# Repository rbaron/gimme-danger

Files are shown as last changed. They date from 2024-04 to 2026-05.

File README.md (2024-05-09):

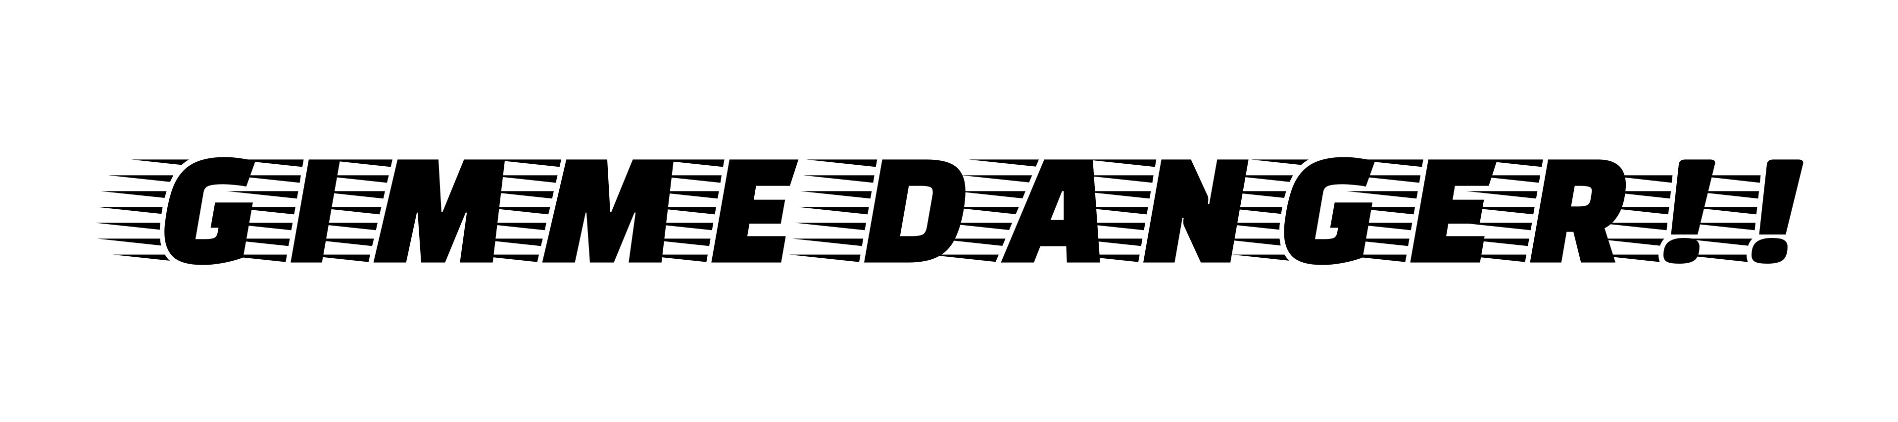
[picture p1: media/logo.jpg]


An open source [USB Power Delivery](https://en.wikipedia.org/wiki/USB_hardware#USB_Power_Delivery) trigger board and 5-channel PWM controller that runs [ESPHome](https://esphome.io).

_GIMME DANGER!!_ negotiates up to 21 V and 3 A[^1] from a USB Power Delivery (USB-PD) capable source -- such as common USB-C wall adapters/chargers and power banks -- and provides controls for its 5 PWM channels, optionally via [Home Assistant](https://home-assistant.io). Each channel can be used to interface with LEDs, motors and more. See below for some video demos.

# Hardware
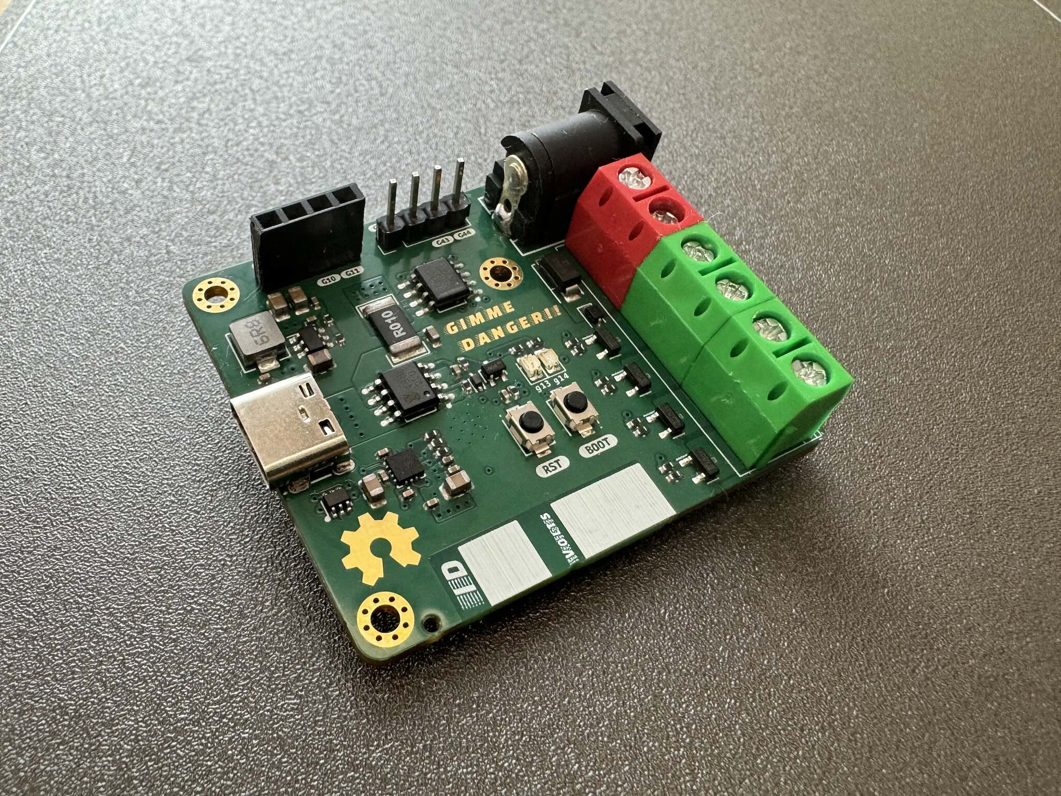
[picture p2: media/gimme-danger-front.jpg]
PCB front

* [ESP32-S3](https://www.espressif.com/en/products/socs/esp32-s3) module, mounted on the [back of the PCB](./media/gimme-danger-back.jpg)
* [FUSB302B](https://www.onsemi.com/products/interfaces/usb-type-c/fusb302b) USB-PD controller
* [INA219](https://www.ti.com/product/INA219) current sensor
* 5 output PWM channels
* 2x5.5mm barrel jack for raw output voltage access
* Optional OLED display

The [`kicad/`](./kicad/) directory contains design files and fabrication files for [JLCPCB](https://jlcpcb.com) manufacturing and assembly. The big through-hole components (headers, power terminals) and the ESP32-S3 module are not included in the assembly, and expected to be soldered by hand.

# Software
A custom `fusb302` component was implemented in ESPHome to support this project. It currently lives in its own fork on [github.com/rbaron/tree/fusb302](https://github.com/rbaron/esphome/tree/fusb302).

Here's a minimal example of using our custom `fusb302` component with ESPHome:

```yaml
external_components:
  - source:
      type: git
      url: https://github.com/rbaron/esphome
      ref: fusb302
    components: [fusb302]

fusb302:
  id: fusb302_id
  i2c_id: i2c_bus_fusb302
  interrupt_pin: GPIO5
  voltage: 12000 mV
  current: 1000 mA
  on_pd_negotiation_success:
    then:
      - switch.turn_on: load_switch
```

Full ESPHome configs for the demos below and more are available in the [`code/`](./code) directory.

# ‼️ Safety disclaimer ‼️
Configuration mistakes or software bugs may toast your devices if a high voltage is accidentally negotiated. While I have never run into these issues, even during development, be extra mindful of this fact then using this project or the `fusb302` component separately. For all intents and purposes, this is an experimental project. Use it at your own risk.

# Supported Power Delivery features
* USB-PD 2.0 Fixed voltages -- 5V, 9V, 12V, 15V, 20V
* USB-PD 3.0 Programmable Power Supply (PPS) -- 3.3V-21V, in 20mV steps (see the power supply demo below)
* USB-PD 3.1 Extended Power Range (EPR) Fixed PDOs -- 28V[^1]

Support for USB-PD 3.1 Adjustable Voltage Supply (AVS) in EPR mode will let us pull 15-28V[^1]. Unfortunately it's still difficult to get our hands on EPR AVS capable sources to implement and test support for it, but in theory the heavy lifting is already done.

# Some use cases & demos
Below there are some demo videos. Click on the images to play.

## 12V LED strip
The main motivation for this project was to power short runs of LED strips from USB-C chargers and control them via Home Assistant. Observing the maximum current and voltage[^1], it should be doable to light up a shelf, table, TV stand or any DYI project that requires only a couple of meters of 12V LED strips. Here [wled-calculator.github.io](https://wled-calculator.github.io/) should help with planning.

In the video below we see _GIMME DANGER!!_ connected to [Home Assistant](https://www.home-assistant.io), controlling a short 12V LED strip.
12V LED Strip (https://youtu.be/a7QtX55lgi8)

## 12V RGBW LED strip
RGBW LED Strip (https://youtu.be/ThnvIa4zbsM)

## A lil' programmable power supply
What's fun is that we can negotiate voltages on the fly from USB-PD 3.0 sources that offer Programmable Power Supply (PPS) modes. Here we have a potentiometer that sets the target voltage, and a button that triggers the USB-PD negotiation for that voltage.

A tiny, experimental and largely untested power supply that's powered by the same USB-C charger as my [soldering iron](https://pine64.com/product/pinecil-smart-mini-portable-soldering-iron/)? Straight into my toolbox.

Power Supply (https://youtu.be/3Acu_VfSuck)

## A Home Assistant controlled power supply
As a display of the flexibility of ESPHome and Home Assistant, we can use _GIMME DANGER!!_ to make a WiFi-controlled power supply. This is an objectively terrible idea, but it's not _GIMME SAFETY!!_ after all. Disregarding the risk of accidentally toasting our loads either via a misclick or a bug, this may be useful for automating the collection of I-V curves.

Home Assistant Power Supply (https://youtu.be/tXYciUaycYI)

# Optional OLED display
There are female pin headers on the board to connect an 0.91" OLED display like [this one from Aliexpress](https://aliexpress.com/item/1005004816561244.html). It's used to display the running voltage and current. There's also a cute animation when negotiation is succesful -- you can see it in the demos above.

# 3D printed case
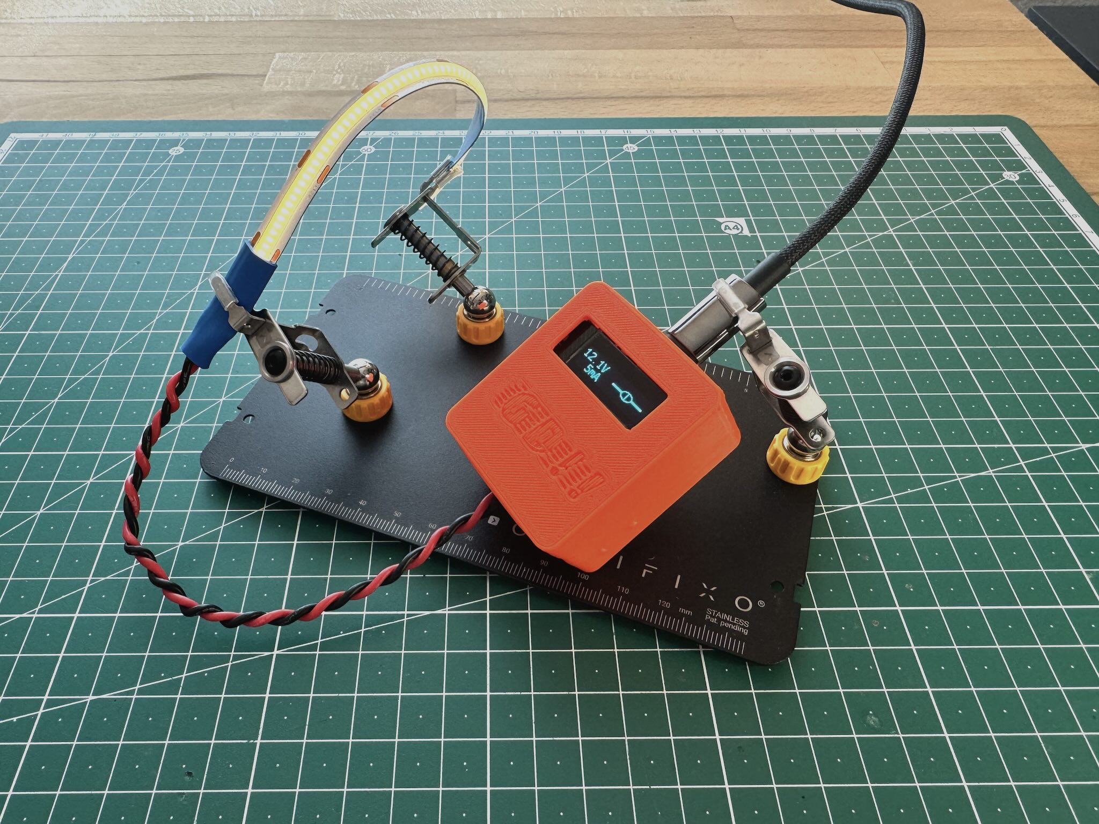
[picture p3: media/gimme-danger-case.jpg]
Case

The [`case/`](./case) directory contains a little 3D printable case. The PCB is optionally held in place by three M2 screws and threaded inserts.

# License
The hardware and associated design files are released under the [Creative Commons CC BY-SA 4.0](https://creativecommons.org/licenses/by-sa/4.0/) license. The code is released under the [MIT license](https://opensource.org/licenses/MIT).

# Attributions
The logo uses the [Faster One](https://fonts.google.com/specimen/Faster+One/about) font, released under the [Open Font License](https://openfontlicense.org/).

[^1]: FUSB302B's typical maximum voltage is 21 V, with 28 V as the absolute maximum. Each PWM channel is rated for 3 A. In theory the board supports up to 5 A, but a safer, better tested range is 21 V / 3 A in total.

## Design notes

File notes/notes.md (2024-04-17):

# Load Switch

Power dissipation:
- P = I^2 * R
- For 5A, Rdson = 30 mOhm, P = 0.75 W, say 1 W

- Digikey search [link](https://www.digikey.com/en/products/filter/single-fets-mosfets/278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)
- [AONR21321](https://aosmd.com/res/data_sheets/AONS21321.pdf)
  - -25 Vgsmax (no zenner needed)
  - 10 amps
  - $ 0.16 on JLCPCB C541711 (but only 260 available)
  - > 3W power dissipation
- [DMP3013](https://www.diodes.com/assets/Datasheets/DMP3013SFV.pdf)
  - -25 Vgsmax (no zenner needed)
  - 10 amps
  - $ 0.33 on JLCPCB (~ 3k available)
  - Only 900 mW of power dissipation?
- [Si7149ADP](https://www.vishay.com/docs/62839/si7149adp.pdf)
  - -25 Vgsmax (no zenner needed)
  - > 3W power dissipation
  - $ 1.30 on JLCPCB (only ~140 available)
- [AON6407](https://aosmd.com/res/data_sheets/AON6407.pdf)
  - -25 Vgsmax (no zenner needed)
  - Very low Rdson ~ 6 mOhm
  - Bigger footprint?
  - 85 A lol -- overkill? But does it matter? Downside: almost double footprint than AONR21321, but still small for us
  - 5W power dissipation
  - $ 0.5 on JLCPCB (7k available) C13899
  - Good choice
- [AO4407A](https://aosmd.com/res/data_sheets/AO4407A.pdf)
  - -25 Vgsmax (no zenner needed)
  - RDs ~ 20 mOhm @ 5 V
  - 12 A
  - > 2W power dissipation
  - $ 0.15 on JLCPCB (10k+ available) C16072
  - SOP-8 package, with the leads it's as big as the AO6407A above...
  - Good choice

### What if we go wild and aim for 3.1 EPR spec with max 48V?
#### Load Switch (P-channel)
- [Digikey search](https://www.digikey.ch/en/products/filter/transistors/fets-mosfets/single-fets-mosfets/278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)
- [DMP6023LE-13](https://wmsc.lcsc.com/wmsc/upload/file/pdf/v2/lcsc/1808280023_Diodes-Incorporated-DMP6023LE-13_C154901.pdf)
  - 28 mOhm
  - 1.3 W power dissipation
  - 1k+ available at JLCPCB
  - Good choice
- [AO4421](https://wmsc.lcsc.com/wmsc/upload/file/pdf/v2/lcsc/1809192244_Alpha---Omega-Semicon-AO4421_C33484.pdf)
  - 50 mOhm
  - 2 W power dissipation
  -
#### Channel Switch (N-channel)
- [AON2260](https://aosmd.com/sites/default/files/res/datasheets/AON2260.pdf)
  - 53 mOhm
  - 60V
  - Vth 2V
  - Rds at 3.3V too high
- [SSM3K341R](https://wmsc.lcsc.com/wmsc/upload/file/pdf/v2/lcsc/2201211430_TOSHIBA-SSM3K341R-LF_C2932178.pdf)
  - Rds at 3.3V too high
- [STS5NF60L](https://wmsc.lcsc.com/wmsc/upload/file/pdf/v2/lcsc/2001151031_STMicroelectronics-STS5NF60L_C457490.pdf)
  - Good, but expensive ($1)
  - Good Rdson at 3.3V, 5A
- [HL6003](https://wmsc.lcsc.com/wmsc/upload/file/pdf/v2/lcsc/2310251707_HL-6003_C7499845.pdf)
  - Works but max current 3A
  - But never heard of this brand
- Looks like we need an external BJT driver...

## Bidirectional switch
- [Digikey search](https://www.digikey.ch/en/products/filter/fet-mosfet-arrays/289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)
- [DMP3098LSD-13](https://jlcpcb.com/partdetail/DiodesIncorporated-DMP3098LSD13/C531177)
  - The one Phil uses
  - Dual P-channel MOSFET
  - Vgsmax = 20 V
  - Vds = -30 V
  - But Id is low: 3.3 A
- [AO4805](https://jlcpcb.com/parts/componentSearch?searchTxt=AO4805)
  - Good choice
  - 25 mOhm (kinda good for 2 MOSFETs)
- [DMP3028LSD-13](https://jlcpcb.com/partdetail/DiodesIncorporated-DMP3028LSD13/C397949)
  - Also good choice
  - Not as many available on JLCPCB

Use a BJT to drive the MOSFET gate?
- Inverts the signal (NOT gate)
- [DDTC1](https://datasheet.lcsc.com/lcsc/2304140030_Diodes-Incorporated-DDTC114EUA-7-F_C177021.pdf)
  - Self-biased (includes base and base-emitter resistors)
  - If we drive with 3.3V,
-

## Design
- [TI's bidirectional design with P-channel MOSFETs](https://www.ti.com/lit/an/slva948/slva948.pdf)
- [nxp load switch basics](https://www.nxp.com/docs/en/white-paper/NXP_Load_Switch_Basics.pdf)

## PWM drivers
Low side switching fine?
No need for high Vgsmax (we only switch between 0 and 3.3V).

- [AO3400A](https://aosmd.com/sites/default/files/res/data_sheets/AO3400A.pdf)
  - 5A
  - ~ 1W power dissipation
- [AON7410](https://datasheet.lcsc.com/lcsc/1808280434_Alpha---Omega-Semicon-AON7410_C269266.pdf)
  - 2W power dissipation
  -

## Barrel Jack
- [54-00131](https://tensility.s3.amazonaws.com/uploads/pdffiles/54-00131.pdf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)
  - 5.5mm OD, 2.1mm ID
  - 6A, 48V
  - Perfect
  - Not available on JLCPCB, but similar [DC-84](https://jlcpcb.com/partdetail/Jinjia-DC84/C718040) is
    - Rated for 2A, 30V only

## Regulator
- [TPS62175](https://www.ti.com/product/TPS62175)
- [TPS62932](https://www.ti.com/product/TPS62932)
  - Newer version
  - TPS62933DRLR
    - 600 available at JLC
    - $0.62
    - C3200405
- [TPS54302](https://www.ti.com/lit/ds/symlink/tps54302.pdf)
  - Cheap, ubiquituous

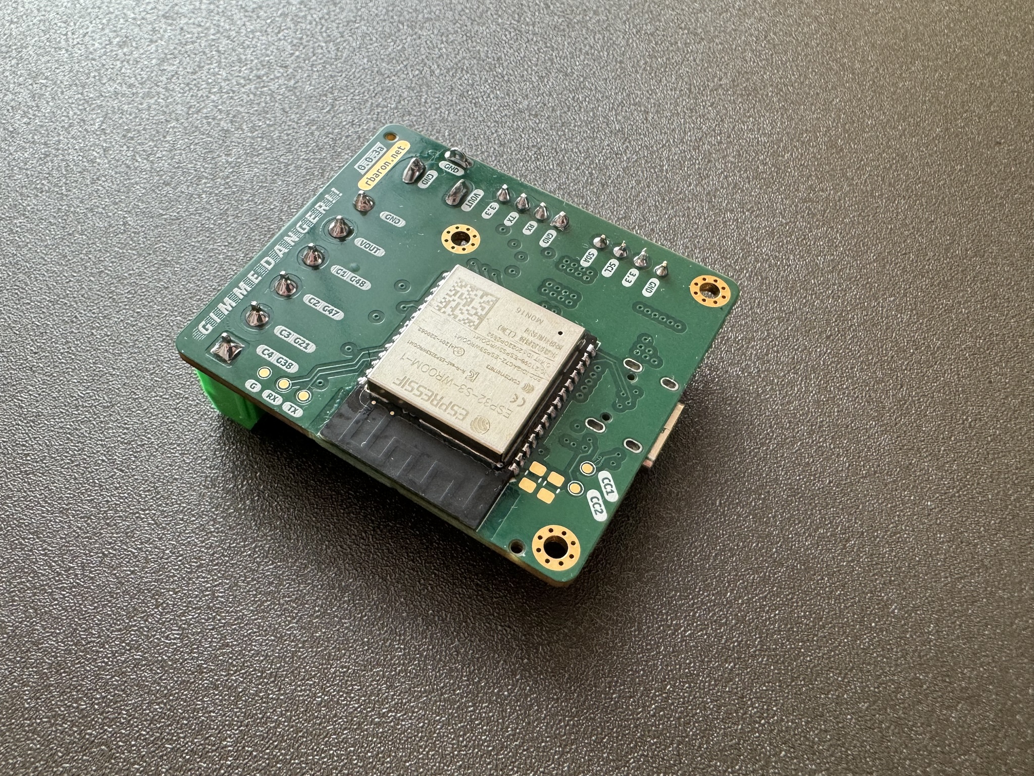
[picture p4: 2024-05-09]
media/gimme-danger-back.jpg

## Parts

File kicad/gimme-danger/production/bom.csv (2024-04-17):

Designator | Footprint | Quantity | Value | LCSC Part #
C1 | 0603 | 1 | 1u | C15849
C10, C14, C15, C2, C3, C9 | 0402 | 6 | 0.1u | C307331
C11, C8 | 0402 | 2 | 220p | C1530
C12 | 0402 | 1 | 1u | C52923
C13, C17, C18, C6 | 0805 | 4 | 22u | C45783
C4 | 0805 | 1 | 10u | C440198
C5, C7 | 0402 | 2 | 0.1u | C1525
D1 | 0805 | 1 | Red | C84256
D2 | 0805 | 1 | Green | C2297
D3 | D_SOD-323 | 1 | 1N5819WS
D4 | SOD-523_L1.2-W0.8-LS1.6-RD | 1 | 18V | C327501
D6 | SMA_L4.3-W2.5-LS5.0-RD | 1 | SMAJ48A | C353444
KEY2 | MLP-14_L2.5-W2.5-P0.50-BL-EP | 1 | FUSB302BMPX | C132291
L1 | IND-SMD_L4.5-W4.5_SMMS0420 | 1 | 6.8uH | C133194
Q1, Q2, Q3, Q4 | SOT-23 | 4 | AO3400A | C347475
R1, R11, R2, R3, R7 | 0402 | 5 | 4k7 | C25900
R10, R19, R20, R9 | 0402 | 4 | 330 | C25104
R12 | 0402 | 1 | 100k | C25741
R13 | 0402 | 1 | 22k | C25768
R14, R15, R17, R18, R4 | 0402 | 5 | 10k | C25744
R22 | 0402 | 1 | 33k | C25779
R23 | 0402 | 1 | 3.3k | C25890
R24 | R2512 | 1 | 10m | C105366
R5, R6 | 0402 | 2 | 1k | C11702
U10 | SOIC-8_L4.9-W3.9-P1.27-LS6.0-BL | 1 | AO4805 | C5183840
U11 | SOT-323-3_L2.0-W1.3-P1.30-LS2.1-BR | 1 | DDTC143EUA | C460045
U2 | USB-C_SMD-TYPE-C-31-M-12 | 1 | TYPE-C-31-M-12 | C165948
U3 | SC-70-6_L2.2-W1.3-P0.65-LS2.1-BL | 1 | TPD4E1U06DCKR | C194628
U5, U7 | SW-SMD_L3.9-W3.0-P4.45 | 2 | SKRKAEE020 | C115357
U8 | SOT-23-6 | 1 | TPS54302 | C311983
U9 | SOIC-8_L4.9-W3.9-P1.27-LS6.0-BL | 1 | INA219AIDR | C138706

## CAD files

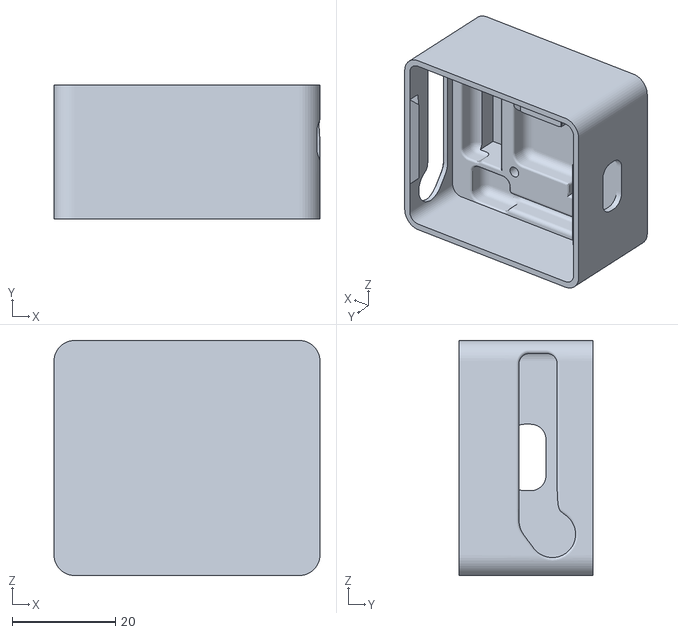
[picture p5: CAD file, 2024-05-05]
case/case.stl
51.5 x 26.0 x 45.5

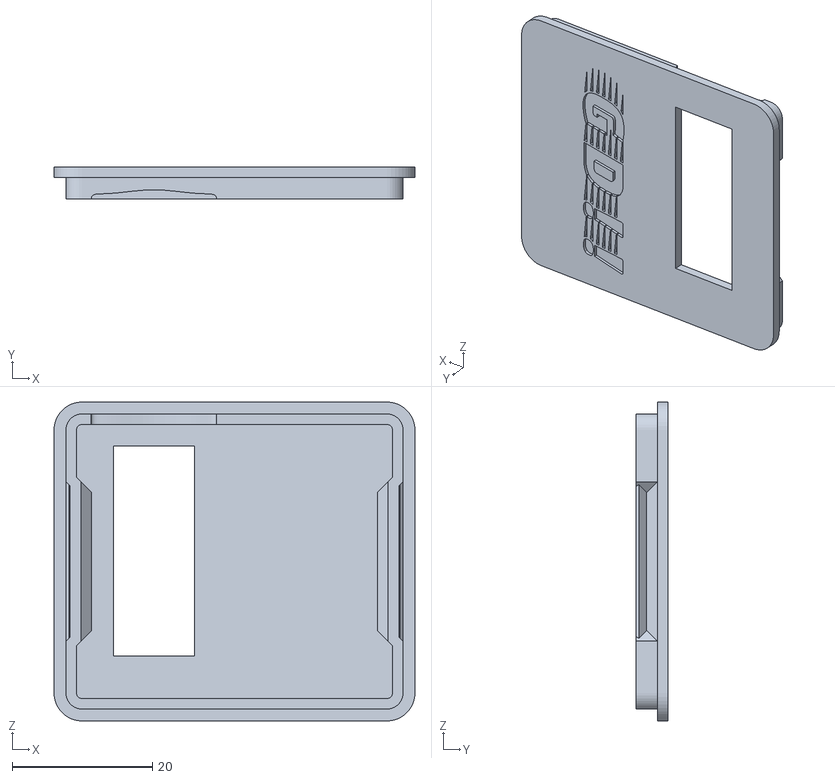
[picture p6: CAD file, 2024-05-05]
case/lid.stl
51.5 x 4.50 x 45.5

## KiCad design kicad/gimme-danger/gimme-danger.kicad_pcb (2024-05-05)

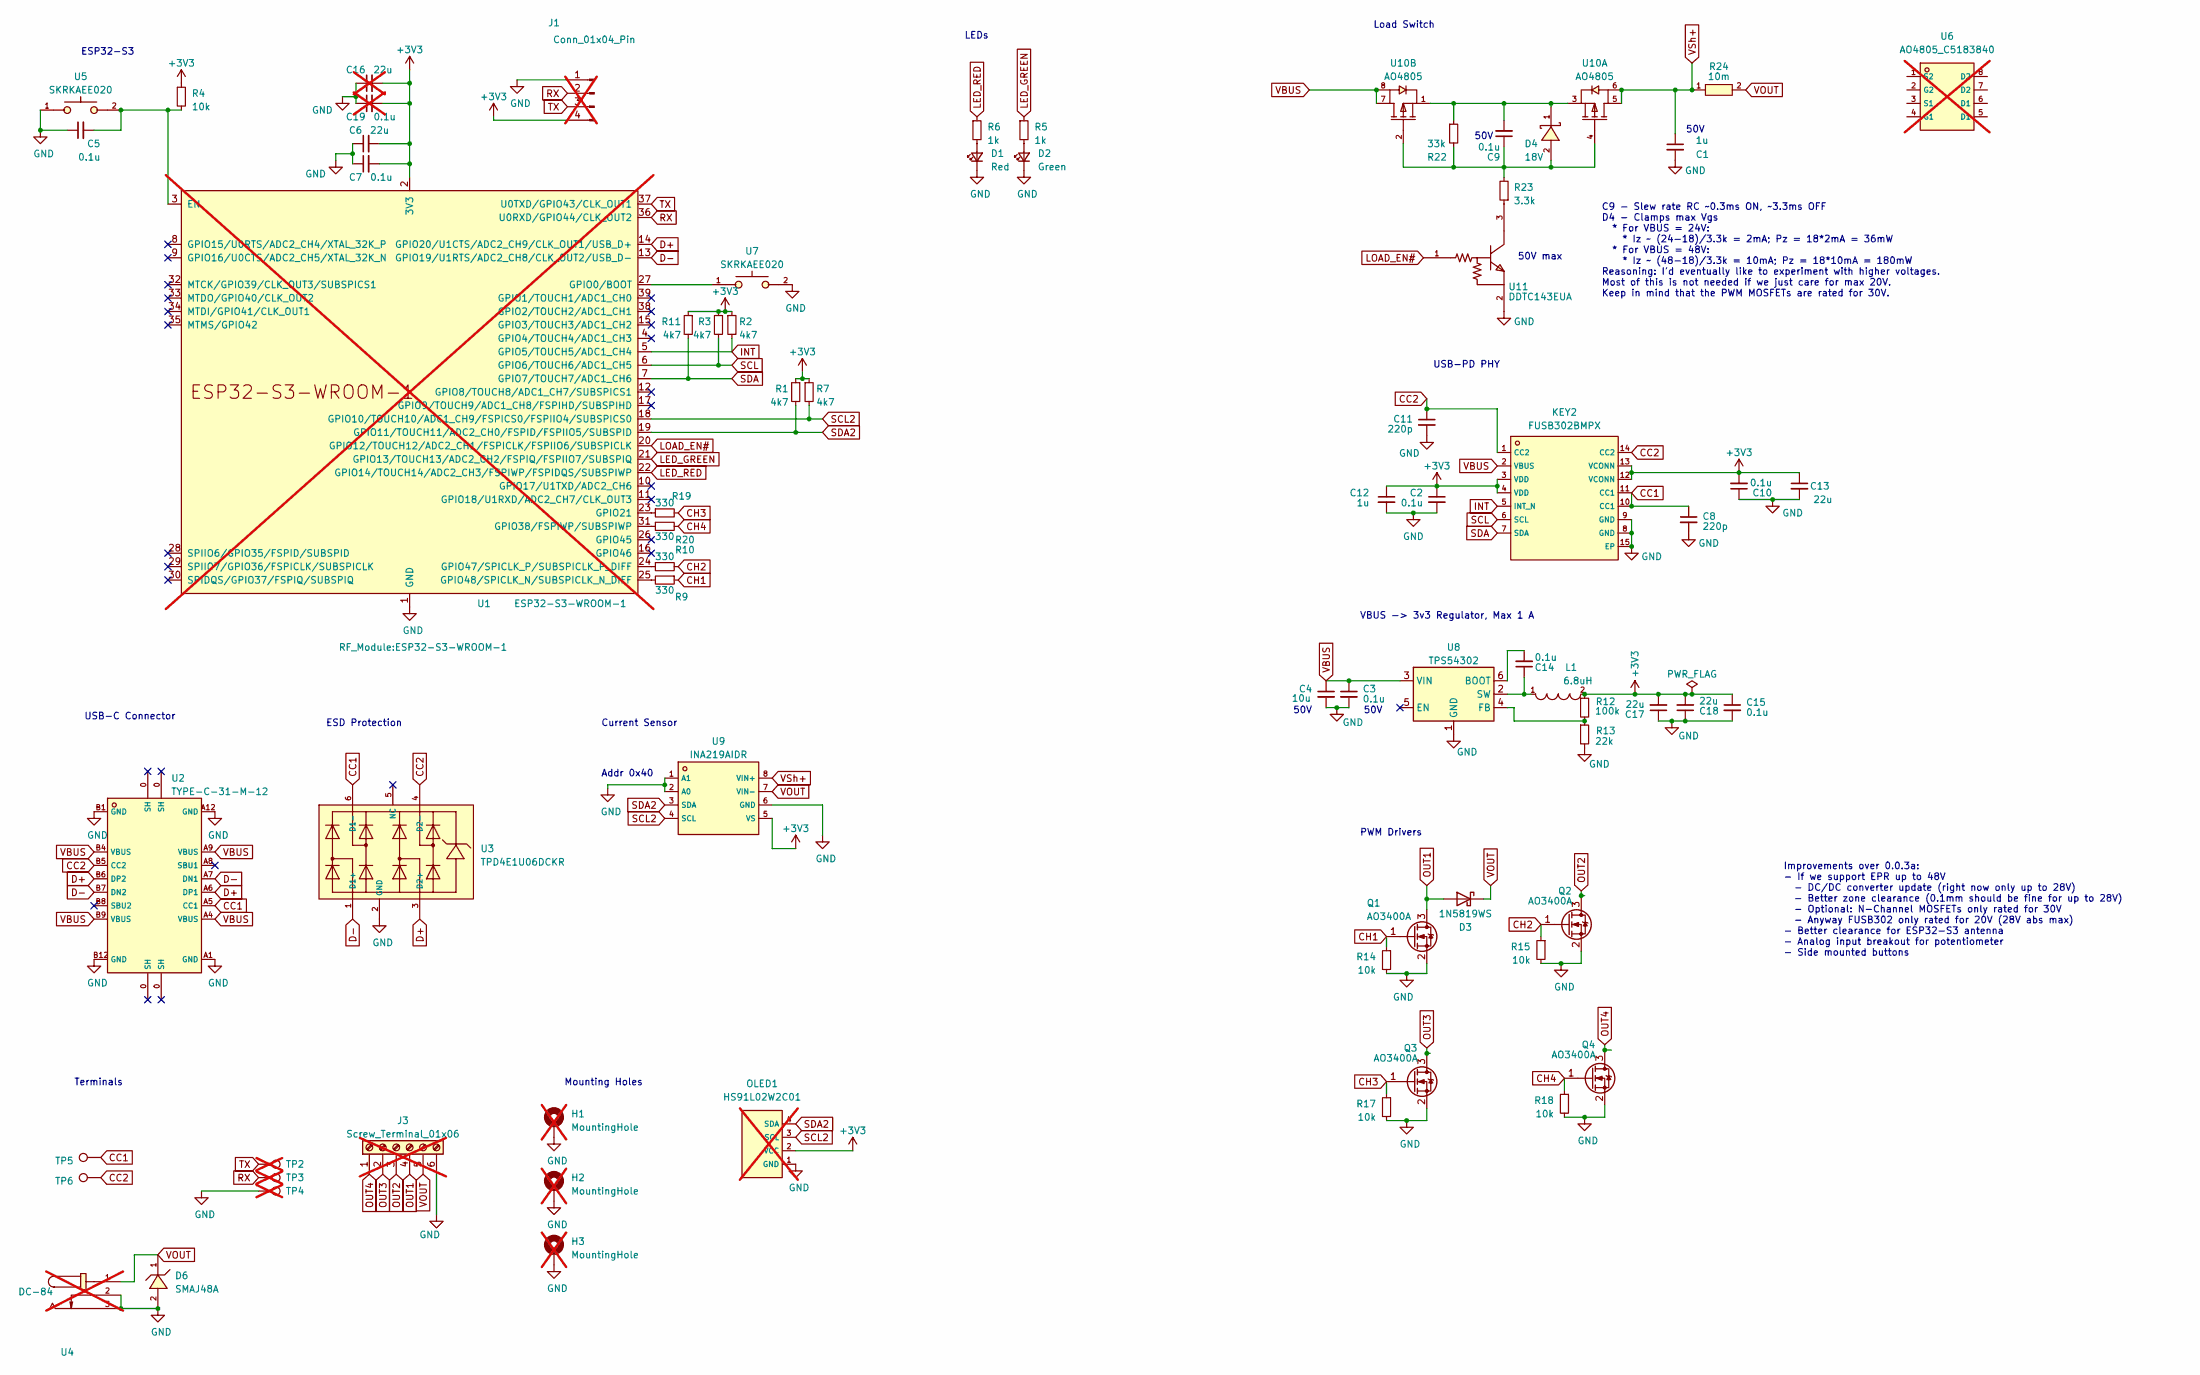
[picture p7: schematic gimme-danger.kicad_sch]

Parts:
C1: 1u; C_0603_1608Metric; LCSC C15849
C2, C3, C9, C10, C14, C15: 0.1u; C_0402_1005Metric; LCSC C307331
C4: 10u; C_0805_2012Metric; LCSC C440198
C5, C7: 0.1u; C_0402_1005Metric; LCSC C1525
C6, C13, C17, C18: 22u; C_0805_2012Metric; LCSC C45783
C8, C11: 220p; C_0402_1005Metric; LCSC C1530
C12: 1u; C_0402_1005Metric; LCSC C52923
C16: 22u; C_0805_2012Metric_Pad1.18x1.45mm_HandSolder; LCSC C45783; not fitted
C19: 0.1u; C_0805_2012Metric_Pad1.18x1.45mm_HandSolder; LCSC C1525; not fitted
D1: Red; LED_0805_2012Metric; LCSC C84256
D2: Green; LED_0805_2012Metric; LCSC C2297
D3: 1N5819WS; D_SOD-323
D4: 18V; SOD-523_L1.2-W0.8-LS1.6-RD; LCSC C327501
D6: SMAJ48A; SMA_L4.3-W2.5-LS5.0-RD; LCSC C353444
H1, H2, H3: MountingHole; MountingHole_2.2mm_M2_Pad_Via; not fitted
J1: Conn_01x04_Pin; PinHeader_1x04_P2.54mm_Vertical; not fitted
J3: Screw_Terminal_01x06; TerminalBlock_Phoenix_MKDS-1,5-6_1x06_P5.00mm_Horizontal; not fitted
KEY2: FUSB302BMPX; MLP-14_L2.5-W2.5-P0.50-BL-EP; LCSC C132291
L1: 6.8uH; IND-SMD_L4.5-W4.5_SMMS0420; LCSC C133194
OLED1: HS91L02W2C01; OLED-TH_L38.0-W12.0_HS91L02W2C01; LCSC C5248081; not fitted
Q1, Q2, Q3, Q4: AO3400A; SOT-23; LCSC C347475
R1, R2, R3, R7, R11: 4k7; R_0402_1005Metric; LCSC C25900
R4, R14, R15, R17, R18: 10k; R_0402_1005Metric; LCSC C25744
R5, R6: 1k; R_0402_1005Metric; LCSC C11702
R9, R10, R19, R20: 330; R_0402_1005Metric; LCSC C25104
R12: 100k; R_0402_1005Metric; LCSC C25741
R13: 22k; R_0402_1005Metric; LCSC C25768
R22: 33k; R_0402_1005Metric; LCSC C25779
R23: 3.3k; R_0402_1005Metric; LCSC C25890
R24: 10m; R2512; LCSC C105366
TP2, TP3, TP4: 3v3; TestPoint_Pad_D1.0mm; not fitted
TP5, TP6: 3v3; TestPoint_Pad_D1.0mm
U1: ESP32-S3-WROOM-1; not fitted
U2: TYPE-C-31-M-12; USB-C_SMD-TYPE-C-31-M-12; LCSC C165948
U3: TPD4E1U06DCKR; SC-70-6_L2.2-W1.3-P0.65-LS2.1-BL; LCSC C194628
U4: DC-84; DC-IN-TH_DC-84; LCSC C718040; not fitted
U5, U7: SKRKAEE020; SW-SMD_L3.9-W3.0-P4.45; LCSC C115357
U6: AO4805_C5183840; SOP-8_L4.9-W3.9-P1.27-LS6.0-BL; LCSC C5183840; not fitted
U8: TPS54302; SOT-23-6; LCSC C311983
U9: INA219AIDR; SOIC-8_L4.9-W3.9-P1.27-LS6.0-BL; LCSC C138706
U10: AO4805; SOIC-8_L4.9-W3.9-P1.27-LS6.0-BL; LCSC C5183840
U11: DDTC143EUA; SOT-323-3_L2.0-W1.3-P1.30-LS2.1-BR; LCSC C460045

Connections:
+3V3: C2.1, C6.2, C7.2, C10.2, C12.1, C13.1, C15.1, C16.2, C17.2, C18.2, C19.2, J1.4, KEY2.3 (VDD), KEY2.4 (VDD), KEY2.12 (VCONN), KEY2.13 (VCONN), L1.2, OLED1.2 (VCC), R1.1, R2.1, R3.1, R4.1, R7.1, R11.1, R12.1, U1.2 (3V3), U9.5 (VS)
CC1: C8.1, KEY2.10 (CC1), KEY2.11 (CC1), TP5.1, U2.A5 (CC1), U3.6 (D1-)
CC2: C11.1, KEY2.1 (CC2), KEY2.14 (CC2), TP6.1, U2.B5 (CC2), U3.4 (D2-)
CH1: Q1.1 (G), R9.1, R14.1
CH2: Q2.1 (G), R10.2, R15.1
CH3: Q3.1 (G), R17.1, R19.2
CH4: Q4.1 (G), R18.1, R20.2
D+: U1.14 (GPIO20/U1CTS/ADC2_CH9/CLK_OUT1/USB_D+), U2.A6 (DP1), U2.B6 (DP2), U3.3 (D2+)
D-: U1.13 (GPIO19/U1RTS/ADC2_CH8/CLK_OUT2/USB_D-), U2.A7 (DN1), U2.B7 (DN2), U3.1 (D1+)
GND: C1.2, C2.2, C3.2, C4.2, C5.1, C6.1, C7.1, C8.2, C10.1, C11.2, C12.2, C13.2, C15.2, C16.1, C17.1, C18.1, C19.1, D1.1 (K), D2.1 (K), D6.2 (A), H1.1, H2.1, H3.1, J1.1, J3.6, KEY2.8 (GND), KEY2.9 (GND), KEY2.15 (EP), OLED1.1 (GND), Q1.2 (S), Q2.2 (S), Q3.2 (S), Q4.2 (S), R13.2, R14.2, R15.2, R17.2, R18.2, TP4.1, U1.1 (GND), U1.40 (GND), U1.41 (GND), U2.A1 (GND), U2.A12 (GND), U2.B1 (GND), U2.B12 (GND), U3.2 (GND), U4.2, U4.3, U5.1, U7.2, U8.1 (GND), U9.1 (A1), U9.2 (A0), U9.6 (GND), U11.2 (GND(0))
INT: KEY2.5 (INT_N), R2.2, U1.5 (GPIO5/TOUCH5/ADC1_CH4)
LED_GREEN: R5.1, U1.21 (GPIO13/TOUCH13/ADC2_CH2/FSPIQ/FSPIIO7/S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)
LED_RED: R6.1, U1.22 (GPIO14/TOUCH14/ADC2_CH3/FSPIWP/FSPIDQS/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)
LOAD_EN#: U1.20 (GPIO12/TOUCH12/ADC2_CH1/FSPICLK/FSPIIO6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), U11.1 (IN)
unnamed: D1.2 (A), R6.2
unnamed: D2.2 (A), R5.2
unnamed: C9.1, D4.2 (A), R22.2, R23.2, U10.2 (G2), U10.4 (G1)
unnamed: C9.2, D4.1 (K), R22.1, U10.1 (S2), U10.3 (S1)
unnamed: C5.2, R4.2, U1.3 (EN), U5.2
unnamed: U1.27 (GPIO0/BOOT), U7.1
unnamed: R19.1, U1.23 (GPIO21)
unnamed: R20.1, U1.31 (GPIO38/FSPIWP/SUBSPIWP)
unnamed: R10.1, U1.24 (GPIO47/SPICLK_P/SUBSPICLK_P_DIFF)
unnamed: R9.2, U1.25 (GPIO48/SPICLK_N/SUBSPICLK_N_DIFF)
unnamed: C14.2, U8.6 (BOOT)
unnamed: R12.2, R13.1, U8.4 (FB)
unnamed: C14.1, L1.1, U8.2 (SW)
unnamed: R23.1, U11.3 (OUT)
OUT1: D3.2 (A), J3.4, Q1.3 (D)
OUT2: J3.3, Q2.3 (D)
OUT3: J3.2, Q3.3 (D)
OUT4: J3.1, Q4.3 (D)
RX: J1.2, TP3.1, U1.36 (U0RXD/GPIO44/CLK_OUT2)
SCL: KEY2.6 (SCL), R3.2, U1.6 (GPIO6/TOUCH6/ADC1_CH5)
SCL2: OLED1.3 (SCL), R7.2, U1.18 (GPIO10/TOUCH10/ADC1_CH9/FSPICS0/FSPIIO4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), U9.4 (SCL)
SDA: KEY2.7 (SDA), R11.2, U1.7 (GPIO7/TOUCH7/ADC1_CH6)
SDA2: OLED1.4 (SDA), R1.2, U1.19 (GPIO11/TOUCH11/ADC2_CH0/FSPID/FSPIIO5/S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), U9.3 (SDA)
TX: J1.3, TP2.1, U1.37 (U0TXD/GPIO43/CLK_OUT1)
VBUS: C3.1, C4.1, KEY2.2 (VBUS), U2.A4 (VBUS), U2.A9 (VBUS), U2.B4 (VBUS), U2.B9 (VBUS), U8.3 (VIN), U10.7 (D2), U10.8 (D2)
VOUT: D3.1 (K), D6.1 (C), J3.5, R24.2, U4.1, U9.7 (VIN-)
VSh+: C1.1, R24.1, U9.8 (VIN+), U10.5 (D1), U10.6 (D1)

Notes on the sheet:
ESD Protection
Mounting Holes
Terminals
50V
Current Sensor
50V max
Improvements over 0.0.3a: - If we support EPR up to 48V - DC/DC converter update (right now only up to 28V) - Better zone clearance (0.1mm should be fine for up to 28V) - Optional: N-Channel MOSFETs only rated for 30V - Anyway FUSB302 only rated for 20V (28V abs max) - Better clearance for ESP32-S3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
USB-C Connector
VBUS -> 3v3 Regulator, Max 1 A
PWM Drivers
LEDs
Load Switch
ESP32-S3
C9 - Slew rate RC ~0.3ms ON, ~3.3ms OFF D4 - Clamps max Vgs * For VBUS = 24V: * Iz ~ (24-18)/3.3k = 2mA; Pz = 18*2mA = 36mW * For VBUS = 48V: * Iz ~ (48-18)/3.3k = 10mA; Pz = 18*10mA = 180mW Reasoning: I'd eventually like to experiment with higher voltages. Most of this is not needed if we just car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
USB-PD PHY
Addr 0x40

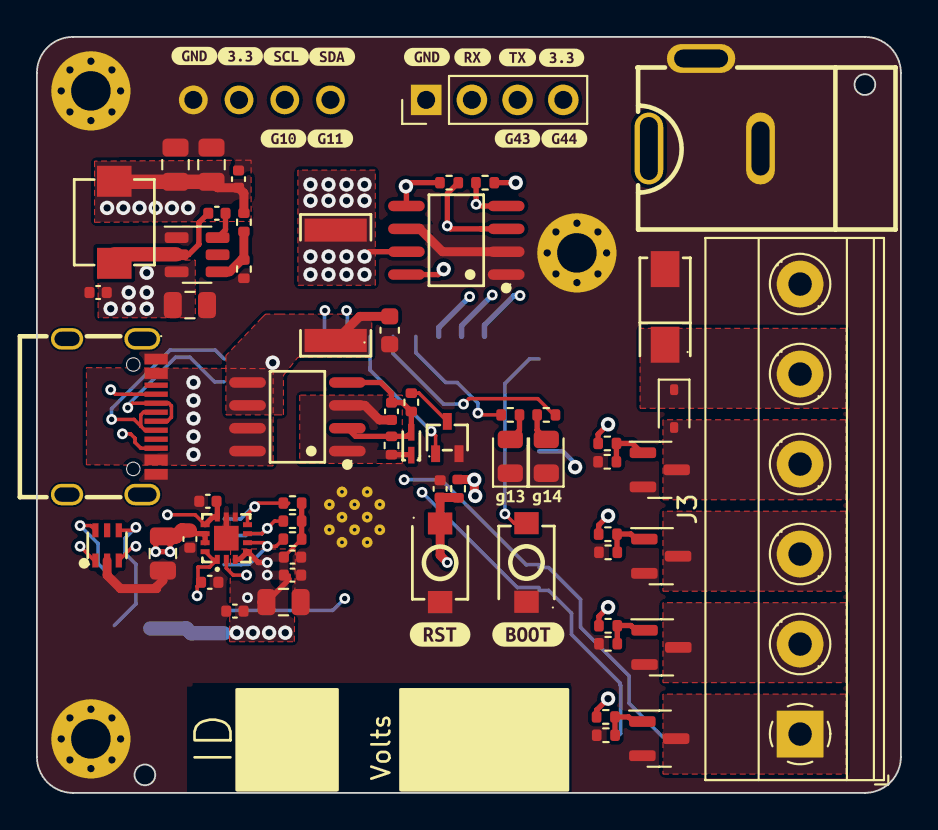
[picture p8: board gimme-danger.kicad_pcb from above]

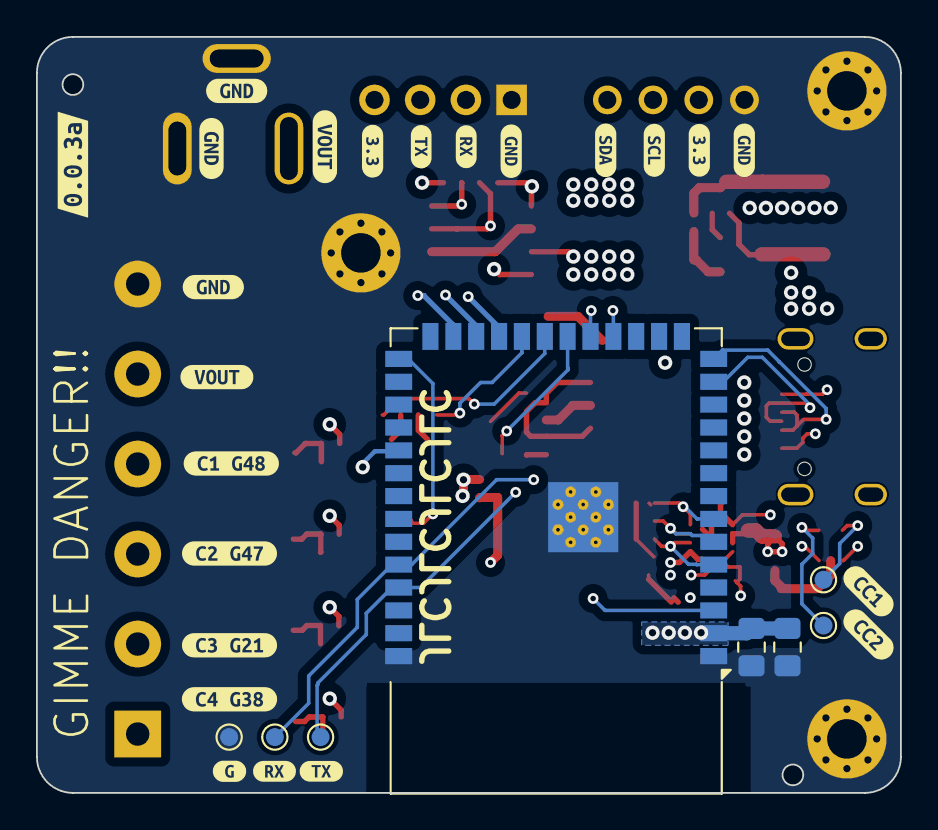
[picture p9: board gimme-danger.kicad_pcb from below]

Board: 4 copper layers, 48.0 x 42.0 mm, 112 parts (32 on the bottom side), 41 nets.

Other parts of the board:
kibuzzard-65EB08A1: G***; kibuzzard-65EB08A1
kibuzzard-65EB08B9: G***; kibuzzard-65EB08B9
kibuzzard-661F8A05, kibuzzard-661F8A05#2: G***; kibuzzard-661F8A05
kibuzzard-661F8A15: G***; kibuzzard-661F8A15
kibuzzard-661F8A20: G***; kibuzzard-661F8A20
kibuzzard-661F8A28: G***; kibuzzard-661F8A28
kibuzzard-661F9CA6: G***; kibuzzard-661F9CA6
kibuzzard-661F9CAC: G***; kibuzzard-661F9CAC
kibuzzard-661F9CB9: G***; kibuzzard-661F9CB9
kibuzzard-661F99AB: G***; kibuzzard-661F99AB
kibuzzard-661F999D: G***; kibuzzard-661F999D
kibuzzard-661F8503: G***; kibuzzard-661F8503
kibuzzard-661F8518: G***; kibuzzard-661F8518
kibuzzard-661F8521: G***; kibuzzard-661F8521
kibuzzard-661F9984: G***; kibuzzard-661F9984
kibuzzard-660044B0, kibuzzard-660044B0#2: G***; kibuzzard-660044B0
kibuzzard-660044E2: G***; kibuzzard-660044E2
kibuzzard-660044E7: G***; kibuzzard-660044E7
kibuzzard-660044F8: G***; kibuzzard-660044F8
kibuzzard-660044FF: G***; kibuzzard-660044FF
kibuzzard-660051B9: G***; kibuzzard-660051B9
kibuzzard-660051C1: G***; kibuzzard-660051C1
kibuzzard-660051C8: G***; kibuzzard-660051C8
kibuzzard-662001DF: G***; kibuzzard-662001DF
kibuzzard-662003AB: G***; kibuzzard-662003AB
kibuzzard-662003BE: G***; kibuzzard-662003BE
kibuzzard-662003E0: G***; kibuzzard-662003E0
kibuzzard-662003F5: G***; kibuzzard-662003F5
kibuzzard-662017BE: G***; kibuzzard-662017BE
kibuzzard-6600450E: G***; kibuzzard-6600450E
kibuzzard-6600453E: G***; kibuzzard-6600453E
kibuzzard-6600454F: G***; kibuzzard-6600454F
kibuzzard-6600455C: G***; kibuzzard-6600455C
kibuzzard-66004518: G***; kibuzzard-66004518
kibuzzard-66004529: G***; kibuzzard-66004529
kibuzzard-66004537: G***; kibuzzard-66004537
kibuzzard-66004547: G***; kibuzzard-66004547
kibuzzard-66004555: G***; kibuzzard-66004555

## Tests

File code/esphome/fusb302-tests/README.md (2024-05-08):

This directory contains tests of the fusb302 component for other platforms than the GIMME DANGER!! board.

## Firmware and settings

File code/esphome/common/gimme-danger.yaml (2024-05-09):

esphome:
  name: gimmedanger003a${gimme_danger_device_id}
  friendly_name: Gimme Danger!! 0.0.3a ${gimme_danger_device_id}
  on_boot:
    - logger.log:
        format: "Gimme Danger!! 0.0.3a ${gimme_danger_device_id}"
        level: WARN
    - delay: 500ms
    - logger.log:
        format: "Starting PD negotiation"
        level: WARN
    - fusb302.start_power_negotiation:
        id: fusb302_id

esp32:
  board: esp32-s3-devkitc-1
  flash_size: 4MB

external_components:
  - source:
      type: git
      url: https://github.com/rbaron/esphome
      ref: fusb302
    components: [fusb302]

i2c:
  - id: i2c_bus_fusb302
    sda: GPIO7
    scl: GPIO6
    scan: False
    frequency: 100kHz
  - id: i2c_bus_ina
    sda: GPIO11
    scl: GPIO10
    scan: False
    frequency: 400kHz

logger:
  hardware_uart: UART0
  level: INFO

output:
  - platform: gpio
    pin:
      number: 13
      mode: output
    id: yellow_led
  - platform: gpio
    pin:
      number: 14
      mode: output
    id: red_led
  - platform: ledc
    id: output_ch1
    pin: GPIO48
  - platform: ledc
    id: output_ch2
    pin: GPIO47
  - platform: ledc
    id: output_ch3
    pin: GPIO21
  - platform: ledc
    id: output_ch4
    pin: GPIO38

switch:
  - platform: gpio
    pin: GPIO12
    id: load_switch
    name: Load Switch
    icon: mdi:flash

sensor:
  - id: ina219_sensor
    platform: ina219
    i2c_id: i2c_bus_ina
    address: 0x40
    shunt_resistance: 0.01 ohm
    current:
      id: ina219_current
      name: "Current"
    power:
      name: "Power"
    bus_voltage:
      id: ina219_load_voltage
      name: "Load Voltage"
    shunt_voltage:
      name: "Shunt Voltage"
    max_voltage: 28.0V
    max_current: 5A
    update_interval: 500ms

fusb302:
  id: fusb302_id
  i2c_id: i2c_bus_fusb302
  interrupt_pin: GPIO5
  voltage: 5000 mV
  current: 1000 mA
  start_power_negotiation_on_boot: false
  on_pd_negotiation_success:
    then:
      - output.turn_on: yellow_led
      - output.turn_off: red_led
      - switch.turn_on: load_switch
  on_pd_negotiation_failure:
    then:
      - output.turn_off: yellow_led
      - output.turn_on: red_led
      - switch.turn_off: load_switch
      - lambda: |-
          ESP_LOGW("fusb302_trigger", "PD negotiation failure outcome: %d", success);

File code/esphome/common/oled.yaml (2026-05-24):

graph:
  - id: current_graph
    sensor: ina219_current
    duration: 10s
    width: 70
    height: 32
    line_thickness: 1
    y_grid: 0.1
    min_value: 0

animation:
  - file: assets/gimme-danger-plug-wave.gif
    id: energy_animation
    type: BINARY
  - file: assets/gimme-danger-load-off.gif
    id: load_off_animation
    type: BINARY

display:
  - id: oled_display
    platform: ssd1306_i2c
    # We can change the display orientation here. Rotation in degrees.
    # rotation: 180
    i2c_id: i2c_bus_ina
    model: "SSD1306 128x32"
    address: 0x3C
    update_interval: 100ms
    pages:
      - id: screen_splash0
        lambda: |-
          // do nothing.
      - id: screen_splash1
        lambda: |-
          it.print(it.get_width() / 2, it.get_height() / 2, id(font_faster), TextAlign::CENTER, "GIMME");
      - id: screen_splash2
        lambda: |-
          it.print(it.get_width() / 2, it.get_height() / 2, id(font_faster), TextAlign::CENTER, "DANGER");
      - id: screen_splash3
        lambda: |-
          it.print(it.get_width() / 2, it.get_height() / 2, id(font_faster), TextAlign::CENTER, "!! ${gimme_danger_device_id}");
      - id: screen_state
        lambda: |-
          if (id(ina219_load_voltage).has_state()) {
            it.printf(0, 0, id(font_small), TextAlign::TOP_LEFT, "%3.1fV ", id(ina219_load_voltage).state);
          }
          if (id(ina219_current).has_state()) {
            if (id(ina219_current).state < 1.0f) {
              it.printf(0, 15, id(font_small), TextAlign::TOP_LEFT, "%3.0fmA", 1000.0f * id(ina219_current).state);
            } else {
              it.printf(0, 15, id(font_small), TextAlign::TOP_LEFT, "%1.1f A", id(ina219_current).state);
            }
          }
          if (id(load_switch).state) {
            it.image(it.get_width() / 2, 0 , id(energy_animation));
            id(energy_animation).next_frame();
          } else {
            it.image(it.get_width() / 2, 0 , id(load_off_animation));
            id(load_off_animation).next_frame();
          }
      - id: screen_current_graph
        lambda: |-
          if (id(ina219_current).has_state()) {
            if (id(ina219_current).state < 1.0f) {
              it.printf(0, it.get_height() / 2, id(font_small), TextAlign::CENTER_LEFT, "%3.0fmA", 1000.0f * id(ina219_current).state);
            } else {
              it.printf(0, it.get_height() / 2, id(font_small), TextAlign::CENTER_LEFT, "%1.1f A", id(ina219_current).state);
            }
          }
          it.graph(it.get_width() - id(current_graph).get_width(), (it.get_height() - id(current_graph).get_height()) / 2 , id(current_graph));

interval:
  - interval: 1s
    startup_delay: 0s
    then:
      - if:
          condition:
            or:
              - display.is_displaying_page:
                  id: oled_display
                  page_id: screen_splash0
              - display.is_displaying_page:
                  id: oled_display
                  page_id: screen_splash1
              - display.is_displaying_page:
                  id: oled_display
                  page_id: screen_splash2
              - display.is_displaying_page:
                  id: oled_display
                  page_id: screen_splash3
          then:
            - display.page.show_next: oled_display
            - component.update: oled_display

font:
  - file: "gfonts://Ubuntu+Mono"
    id: font_small
    size: 18
  - file: "gfonts://Faster+One"
    id: font_faster
    size: 25

binary_sensor:
  - platform: gpio
    pin:
      number: GPIO0
      inverted: True
      mode:
        input: true
        pullup: true
    name: Boot Button
    filters:
      - delayed_on: 10ms
      - delayed_off: 10ms
    on_press:
      then:
        - display.page.show_next: oled_display
        - component.update: oled_display

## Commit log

2023-11-22 Forked sample, added nucleo_g071rb.overlay
    Miraculously it compiles? Still I need to wait for the nucleo_g071rb
    board. It should arrive tomorrow.
2024-01-15 Initial kicad project -- just main ICs
    [gimme-danger.kicad_pcb, gimme-danger.kicad_sch]
2024-01-15 Set up page details
    [gimme-danger.kicad_pcb, gimme-danger.kicad_sch]
2024-01-19 Add NX20P5090 IC for switching
    [gimme-danger.kicad_pcb, gimme-danger.kicad_sch]
2024-01-20 First pass on schematics -- needs double checking, esp decoupling caps
    [gimme-danger.kicad_pcb, gimme-danger.kicad_sch]
2024-01-21 Second pass on schematics
    [gimme-danger.kicad_sch]
2024-01-21 Changed to more capable DC-DC converter (up to 1.2A)
    Worst case: ESP32-S3 500 mA + FUSB302 500 mA
    [gimme-danger.kicad_pcb, gimme-danger.kicad_sch]
2024-01-24 Initial partial routing
    But I'm not convinced I can route the tiny load switch well. I will
    change it back to the same setup as used by luz.
    [gimme-danger.kicad_pcb, gimme-danger.kicad_sch]
2024-03-06 Schematic with FUSB302 kinda finished
    [gimme-danger.kicad_sch]
2024-03-06 Better schematic layout
    [gimme-danger.kicad_sch]
2024-03-07 Initial partial routing
    [gimme-danger.kicad_pcb, gimme-danger.kicad_sch]
2024-03-07 Initial routing
    Many issues :|
    [gimme-danger.kicad_pcb, gimme-danger.kicad_sch]
2024-03-07 DRC kinda passes
    [gimme-danger.kicad_pcb]
2024-03-08 Minor routing fixes
    [gimme-danger.kicad_pcb]
2024-03-08 Routed new output: 4 channels
    [gimme-danger.kicad_pcb, gimme-danger.kicad_sch]
2024-03-08 Better ground return path for all channels
    [gimme-danger.kicad_pcb, gimme-danger.kicad_sch]
2024-03-08 Removed some unconnected tracks
    [gimme-danger.kicad_pcb]
2024-03-08 v0.0.1a maybe?
    [gimme-danger.kicad_pcb]
2024-03-08 No mo 0.2 vias -> 0.3 vias
    [gimme-danger.kicad_pcb, gimme-danger.kicad_sch]
2024-03-08 Fixes DRC errors
    [gimme-danger.kicad_pcb, gimme-danger.kicad_sch]
2024-03-08 Moar VBus zone
    [gimme-danger.kicad_pcb]
2024-03-10 Production 0.0.1a
    [bom.csv, designators.csv, gimme-danger.kicad_pcb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]
2024-03-15 Blinky kinda works! But boards needs revision...
    [gimme-danger.kicad_sch]
2024-03-17 (Fixed) PD negotiation and V out monitor works :)
    [gimme-danger.kicad_sch]
2024-03-22 YAML for 4 channels + wifi + fusb302
    [gimme-danger.kicad_sch]
2024-03-23 New load switch design
    [gimme-danger.kicad_sch]
2024-03-24 TVS diodes on output
    [gimme-danger.kicad_sch]
2024-03-24 Added mounting holes
    [gimme-danger.kicad_sch]
2024-03-24 v0.0.2a routing v0
    [gimme-danger.kicad_pcb, gimme-danger.kicad_sch]
2024-03-24 Board outline is round number of mms
    [gimme-danger.kicad_pcb]
2024-03-24 Add schottky on ch1
    [gimme-danger.kicad_pcb, gimme-danger.kicad_sch]
2024-03-24 No more DRC errors -- only 78 warnings
    [gimme-danger.kicad_pcb, gimme-danger.kicad_sch]
2024-03-24 Routing 0.0.2a v1
    No DCR errors
    [gimme-danger.kicad_pcb, gimme-danger.kicad_sch]
2024-03-25 Changed PWM drivers gate resistor to 330
    Minor routing changes
    [gimme-danger.kicad_pcb, gimme-danger.kicad_sch]
2024-03-25 v0.0.2a fabrication
    [bom.csv, designators.csv, gimme-danger.kicad_pcb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]
2024-04-01 Updated to KiCad 8
    Also updated ESP32-S3 footprint/model
    [gimme-danger.kicad_pcb, gimme-danger.kicad_sch]
2024-04-05 Add case
    [case.stl, gimme-danger.kicad_sch, lid.stl]
2024-04-15 Kicad comments
    [gimme-danger.kicad_sch]
2024-04-17 First routing of 0.0.3a
    [gimme-danger.kicad_pcb, gimme-danger.kicad_sch]
2024-04-17 DRC passes for 0.0.3a
    [gimme-danger.kicad_pcb, gimme-danger.kicad_sch]
2024-04-17 Final touches on 0.0.3a
    [gimme-danger.kicad_pcb]
2024-04-17 Minor tweaks
    [bom.csv, designators.csv, gimme-danger.kicad_pcb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]
2024-04-17 Fabrication output for 0.0.3a
    [bom.csv, designators.csv, gimme-danger.kicad_sch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]
2024-05-05 Don't ask
    [case.stl, gimme-danger.kicad_pcb, gimme-danger.kicad_sch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]
2024-05-09 It works on raspberry pi pico!
2024-05-09 It works on esp32-c6
